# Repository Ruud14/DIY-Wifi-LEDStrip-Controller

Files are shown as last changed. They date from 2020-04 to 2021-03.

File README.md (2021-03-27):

# DIY Wi-Fi LEDStrip Controller

Project status: Work in progress.

DIY Wi-Fi LED strip controller based on the ESP32 chip and MicroPython. Contains step-by-step build guide with links to parts. The controller can be controlled via raw sockets or with an android app.

### Parts
- 1x NodeMCU ESP32 : [eBay LINK 1pc](https://www.ebay.com/itm/Espressif-ESP32-WLAN-Dev-Kit-Board-Development-Bluetooth-Wifi-v1-WROOM32-NodeMCU/253059783728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)
- 3x 1KOhm resistor: [eBay LINK 100pc](https://www.ebay.com/itm/100-pcs-1-4W-0-25W-1-Metal-Film-Resistor-1K-ohm-1Kohm/282033455842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)
- 1x 12v Female DC Power Socket: [EBAY LINK 10pc](https://www.ebay.com/itm/10Pcs-5-5-x-2-1mm-12-V-DC-Power-Supply-Jack-Socket-Female-Panel-Mount-Connector/143449192665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)
- 1x Female strip connector: [EBAY LINK 5pc](https://www.ebay.com/itm/Durable-4Pin-Male-Female-Connector-Wire-Cable-for-3528-5050-SMD-LED-Strip-Light/352235582745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)
- 1x RGB LED strip: [eBay LINK 1pc](https://www.ebay.com/itm/184203854470?ViewItem=&item=184203854470)
- 3x Tip31c transistor: [eBay LINK 10pc](https://www.ebay.com/itm/10-x-TIP31C-TIP31-NPN-Transistor-3A-100V-TO-220-FSC/270984720497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)
- 1x 12v Power Supply Adapter (2A for a 5M long strip): [eBay LINK 1pc](https://www.ebay.com/itm/AC-TO-DC-5V-12V-24V-1A-2A-3A-5A-10A-0-5A-Power-Supply-Adapter-LED-Strip-Light/254344416209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)
- 1x 12v to 5v Converter: [eBay LINK 1pc](https://www.ebay.com/itm/DC-DC-12V-to-5V-6V-9V-2-3A-15W-Converter-Step-Down-2A-3A-15W-Power-Supply-Module/401327863545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)
- 1x PCB. Upload the attached Gerber files to jlcpcb.com. (Minimum amount is 5pc)
- 8x M2.5-3.5 bolts&nuts. 20-30 mm long [eBay LINK](https://www.ebay.com/itm/M2-M2-5-M3-304-Stainless-Steel-Allen-Hex-Socket-Countersunk-Head-Screws-Bolts/282935136527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)
- 2x Simple 5 cm long wire

### Tools
- Soldering iron
- small pliers (or tiny hands)
- 3d printer (optional, you can make everything except for the case.)
- Windows or Linux PC.

# Makers guide
First order all the necessary parts and make sure you have all the required tools.
While waiting for the parts to arrive you can already install a version of [python](https://www.python.org/) on your PC.
Make sure you install version 3.7 or higher.
After installing python you can connect your esp32 board to your PC using a micro USB cable,
install [esptool](https://pypi.org/project/esptool/) and flash your esp32 with the MicroPython firmware. You can find a great guide for all this
over [here](https://docs.micropython.org/en/latest/esp8266/tutorial/intro.html). **Make sure to hold the "Boot" button on the board while writing and erasing flash or it won't work.**

The last thing we should do before we start soldering is put
the [attached scripts](https://github.com/Ruud14/DIY-Wifi-LEDStrip-Controller/tree/master/to_ESP32) on the board.
You can do this with a tool called [ampy](https://learn.adafruit.com/micropython-basics-load-files-and-run-code/install-ampy) .
Simply install ampy by running 'pip3 install adafruit-ampy' in your terminal. After that you can put all the scripts on your board by running:
'ampy --port YOUR_PORT put boot.py',
'ampy --port YOUR_PORT put main.py',
'ampy --port YOUR_PORT put objects.py',

After this you can disconnect your esp32 from your PC and start soldering.
I tried to mark everything on the PCB as good as possible, but you can look at the [pictures](https://github.com/Ruud14/DIY-Wifi-LEDStrip-Controller/tree/master/pictures) if it isn't clear enough.
**One thing you really need to look out for is that the wires of the female strip connector aren't in the correct order.
You need to put the red wire in the hole that says 'R', the green one in the hole that says 'G' and the blue one in the hole that says 'B'.**
**Another thing to note is that the shortest end of the female dc power socket should be connected to the positive end of the board**

*This part is for the ones that are printing the case.
You can download the [attached .stl files](https://github.com/Ruud14/DIY-Wifi-LEDStrip-Controller/tree/master/3d%20models)
convert them to g-code and print them. Make sure you enable support material for the bottom part.*

After everything is done you should check that no soldered connections are touching each other and connect your soldered PCB to power.
Just to check you can scan for nearby Wi-Fi networks on your phone and you should see a network called "LedStrip Setup" if everything is alright.
Now your very own controller is done and you can install the app to control the strip [here](https://github.com/Ruud14/Wifi-LEDStrip-Controller-App).
You can also control the strip by sending raw socket commands in the following format:

(1024,0,0);Fade(0.2);(0,0,0);Wait(0.2)

The string should always start with a RGB color '(r,g,b)'
where the values of r, g and b must be between 0 and 1024.
After a color comes a transition. The two options are 'Fade(x)' and 'Wait(x)' .
A color can only be followed up by a transition and a transition can only be followed up by a color.
Colors and transitions must be separated by a ';'. The string must always end with a transition.

**Just to make sure that the ip of your strip controller doesn't change when the router resets, Reserve the ip addresses of the strip controller in the settings of your router.** You can find the ip of your controller in [The android app](https://github.com/Ruud14/Wifi-LEDStrip-Controller-App) after you added the strip.

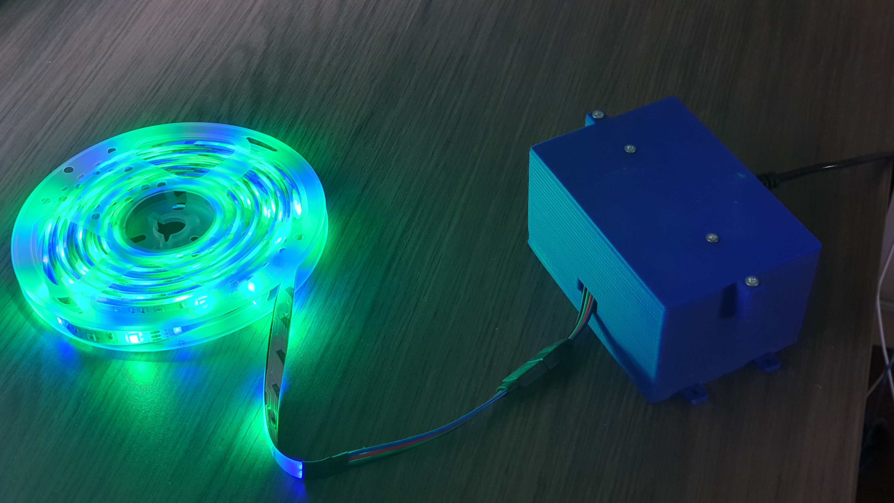
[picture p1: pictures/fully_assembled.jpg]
fully_assembled

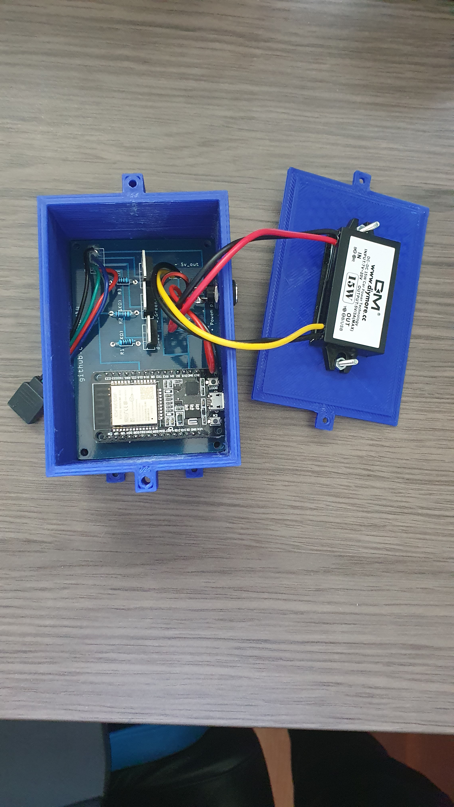
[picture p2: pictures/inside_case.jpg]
inside_case

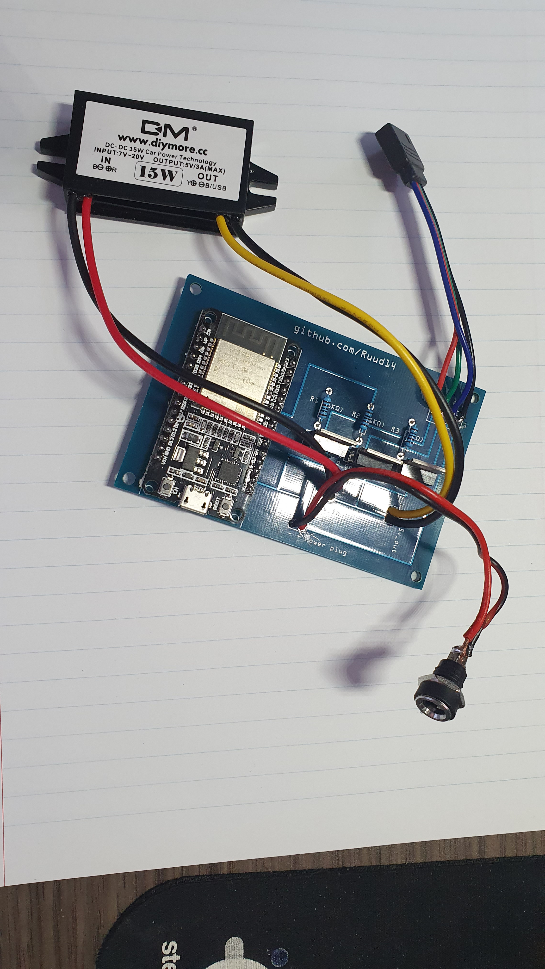
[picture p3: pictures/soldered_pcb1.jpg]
soldered_pcb1


### Additional info.
**What I learned:**
- Working access point networks.
- Working with the esp32 (Had used a esp8266 before).
- Designing a PCB.

Licensed under the [MIT License](https://github.com/Ruud14/DIY-Wifi-LEDStrip-Controller/blob/master/LICENSE)

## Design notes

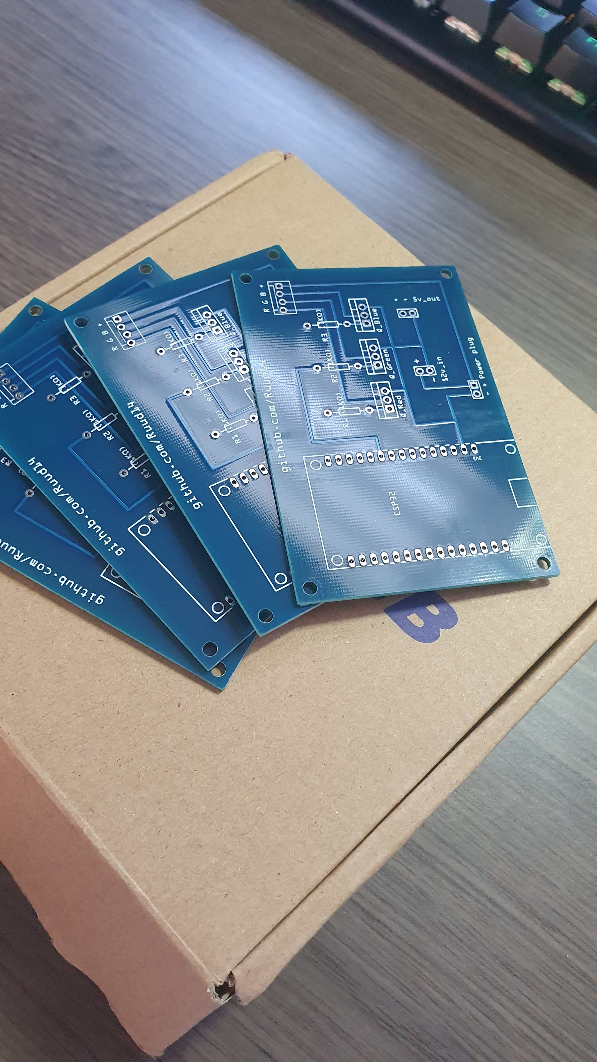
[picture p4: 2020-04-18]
pictures/pcbs.jpg

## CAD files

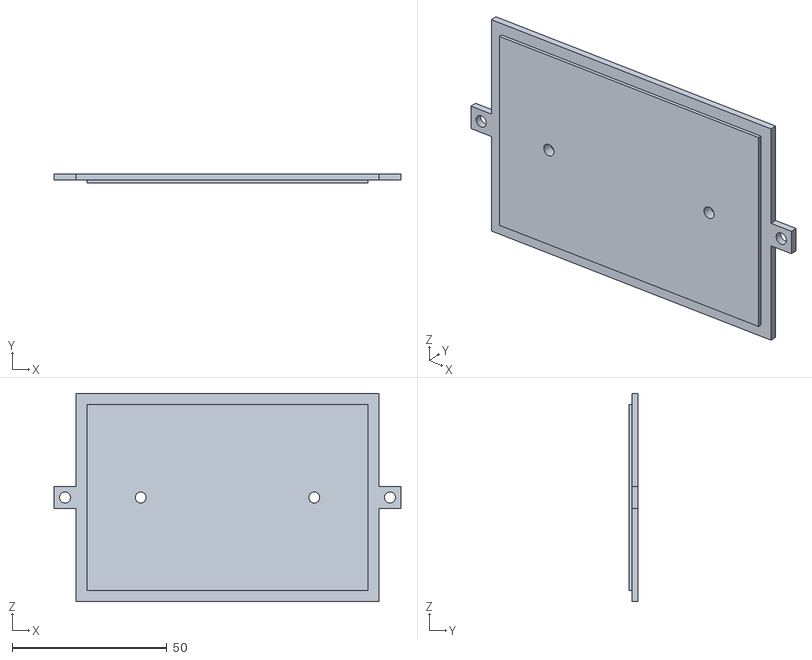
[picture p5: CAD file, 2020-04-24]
3d models/Top.stl
112.2 x 3.06 x 67.3

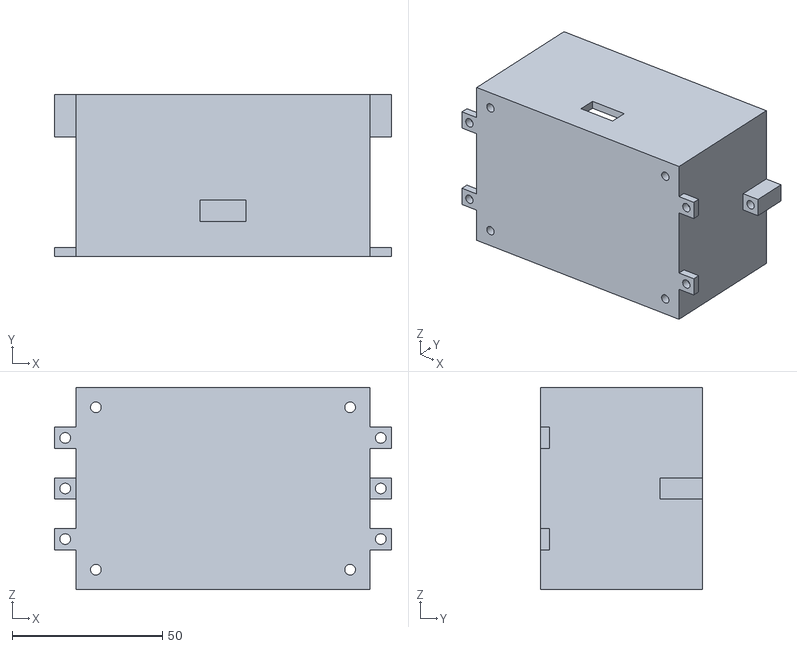
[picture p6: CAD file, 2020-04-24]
3d models/Bottom.stl
112.2 x 54.1 x 67.3

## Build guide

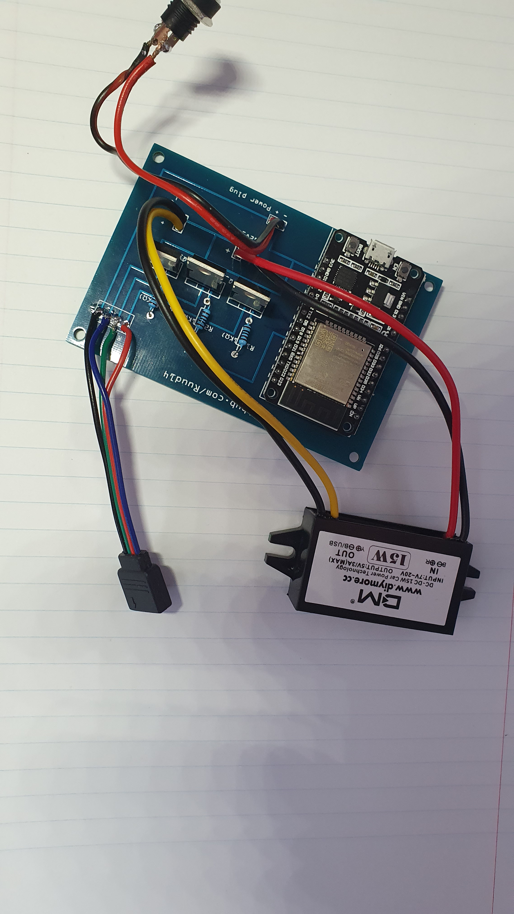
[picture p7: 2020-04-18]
pictures/soldered_pcb2.jpg

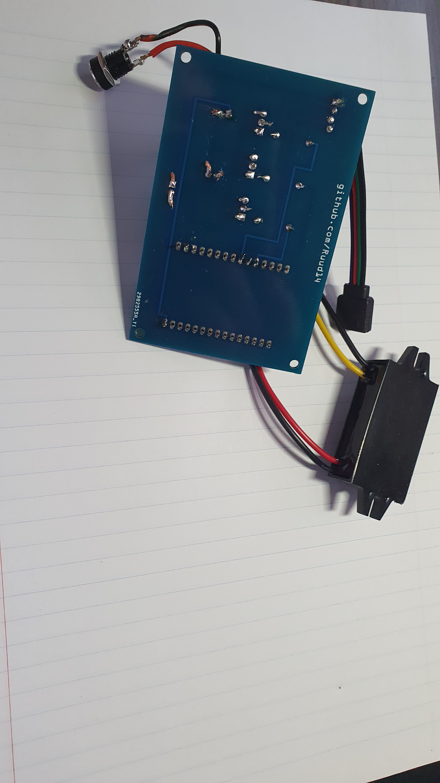
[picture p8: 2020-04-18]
pictures/soldered_pcb3.jpg

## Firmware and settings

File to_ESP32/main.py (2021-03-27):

import _thread
from objects import *
import usocket
import machine
import time
import gc
import os

CONFIGURATION_SAVE_FILE = "configurations.save"
NETWORK_CONFIGURATION_SAVE_FILE = "netconfig.txt"
DATA_PORT = 8778


def create_socket():
    s = usocket.socket()
    s.bind(("0.0.0.0",DATA_PORT))
    s.listen(5)
    return s


# Load the last saved configuration if there is one. Otherwise load a red flashing one.
def get_last_configuration():
    try:
        with open(CONFIGURATION_SAVE_FILE, 'r') as file:
            str_loops = file.readlines()
        config = load_configuration(str_loops[-1])
    except (OSError, IndexError, ValueError):
        config = [Color(1023, 0, 0), Wait(0.2), Color(0, 0, 0), Wait(0.2), Color(1023, 0, 0), Wait(0.2),
                      Color(0, 0, 0), Wait(1.0)]
    return config


def main():
    s = create_socket()
    s.settimeout(2)
    start_loop = get_last_configuration()

    c = Configuration(start_loop, CONFIGURATION_SAVE_FILE)
    _thread.start_new_thread(c.play_forever, ())

    while True:
        try:
            client, addr = s.accept()
            message = client.recv(4096).decode()

            # Reboots the chip.
            if message == "restart":
                machine.reset()
                continue
            elif message == "status":
                if c.stopped:
                    client.send('0')
                else:
                    client.send('1')
                time.sleep(0.1)
                continue
            # Resets network settings and configurations.
            elif message == "reset":
                os.remove(NETWORK_CONFIGURATION_SAVE_FILE)
                os.remove(CONFIGURATION_SAVE_FILE)
                c.stop()
                machine.reset()
                continue
            elif message == "off":
                for i in range(10):
                    c.stop()
                    time.sleep(0.1)
                continue
            elif message.startswith('('):
                str_configuration = message
            else:
                continue
        except OSError:
            continue
        # Close the client if there is one.
        finally:
            try:
                client.close()
            except NameError:
                pass
        c.stop()
        gc.collect()
        # Keep the current loop if the new one is invalid.
        try:
            loop = load_configuration(str_configuration)
            c.loop = loop
            c.validity_check()
        except:
            c.loop = get_last_configuration()
        c.save()
        c.restart()


if __name__ == '__main__':
    main()

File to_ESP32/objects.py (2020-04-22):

import time
import sys
import machine

RED_CONTROL_PIN = 21
GREEN_CONTROL_PIN = 19
BLUE_CONTROL_PIN = 18


def error(arg):
    raise Exception(arg)


# Converts a (saved or received) configuration from a string to the loop argument of the Configuration class.
def load_configuration(str_conf):
    str_loop = str_conf.split(";")
    loop = []
    for x in str_loop:
        if x.startswith("("):
            loop.append(Color(*[int(y)-1 if int(y)==1024 else int(y) for y in x.replace(")","").replace("(","").split(",")]))
        else:
            class_name, duration = x.split("(")
            duration = float(duration.replace(")",""))
            loop.append(getattr(sys.modules[__name__], class_name)(duration))
    return loop


class Color:
    def __init__(self, R, G, B):
        self.validity_check(R, G, B)
        self.set(R, G, B)

    # Sets the current color of the strip.
    def set(self, R, G, B):
        self.R = int(round(R))
        self.G = int(round(G))
        self.B = int(round(B))
        led_strip.set_color(self)

    # Returns the color as r,g,b values.
    def get(self):
        return self.R, self.G, self.B

    # Checks if the R,G,B values are valid.
    def validity_check(self, R, G, B):
        if not R >= 0 or not R <= 1023 or not G >= 0 or not G <= 1023 or not B >= 0 or not B <= 1023:
            error("The value of R, G and B have to be between 0 and 1023: {},{},{}".format(R, G, B))

    def __str__(self):
        return str((self.R, self.G, self.B))


# ---- Transition parent class ---- #
class Transition:
    def __init__(self, duration):
        self.duration = duration
        self.current_color = Color(0, 0, 0)

    # Returns the current color.
    def get(self):
        return self.current_color

    def __str__(self):
        return str(self.__class__.__name__)+"({})".format(self.duration)


# ---- All transitions ----
# Waits for a specific amount of seconds before changing to the next color.
class Wait(Transition):
    def run(self, current_color, next_color):
        self.current_color = current_color
        time.sleep(self.duration)
        self.current_color.set(*next_color.get())


# Slowly fades from one color to another during a specific amount of seconds.
class Fade(Transition):
    def run(self, current_color, next_color):
        self.current_color = current_color
        differences = [0, 0, 0]
        for i in range(3):
            differences[i] = next_color.get()[i] - self.current_color.get()[i]
        iterations = int(self.duration*1000)
        part = 1/iterations
        start = self.current_color.get()

        for i in range(iterations):
            self.current_color.set(start[0] + part * differences[0] * (i+1), start[1] + part * differences[1] * (i+1), start[2] + part * differences[2] * (i+1))
            time.sleep(0.001)
        self.current_color.set(*next_color.get())


# Class representation of the LED strip.
class LedStrip:
    def __init__(self, r_pin, g_pin, b_pin):
        self.red = machine.PWM(machine.Pin(r_pin), freq=5000)
        self.green = machine.PWM(machine.Pin(g_pin), freq=5000)
        self.blue = machine.PWM(machine.Pin(b_pin), freq=5000)

    # Sets the color of the strip.
    def set_color(self, color):
        r,g,b = color.get()
        self.red.duty(r)
        self.green.duty(g)
        self.blue.duty(b)


# Class representation of the configuration running on the strip.
class Configuration:
    def __init__(self, loop, save_file):
        self.save_file = save_file
        self.loop = loop
        self.validity_check()
        self.save()
        self.current_color = Color(*loop[0].get())
        self.stopped = False

    # Goes through self.loop to play the configuration
    def play(self):
        for i, it in enumerate(self.loop):
            if isinstance(it, Transition):
                if self.stopped:
                    break
                try:
                    if i == len(self.loop)-1:
                        it.run(self.current_color, self.loop[0])
                    else:
                        it.run(self.current_color, self.loop[i+1])
                except IndexError:
                    break

    # Keeps running self.play to play the configuration forever
    def play_forever(self):
        while True:
            if not self.stopped:
                self.play()

    # stops running the configuration and turns off the strip.
    def stop(self):
        self.stopped = True
        self.current_color = Color(0, 0, 0)

    # Continues running the configuration.
    def restart(self):
        self.stopped = False

    # Saves the current configuration to storage so it can be run on the next startup.
    def save(self):
        string = ";".join([str(x) for x in self.loop]) + "\n"
        print(string)

        try:
            with open(self.save_file, 'r+') as file:
                last = file.readlines()[-1]
                # only save if the last save isn't the same as this one.
                if not last == string:
                    file.write(string)
            with open(self.save_file, 'r') as file:
                data = file.readlines()
            # save only 5 configurations.
            if len(data) > 5:
                with open(self.save_file, 'w') as file:
                    for line in data[1:]:
                        file.write(line)
        except (OSError, IndexError):
            with open(self.save_file, 'w') as file:
                file.write(string)

    # Checks if the configuration is valid.
    def validity_check(self):
        if not isinstance(self.loop[0], Color):
            error("First element of loop has to be a color.")
        if not isinstance(self.loop[-1], Transition):
            error("Last element of loop has to be a transition. "
                  "This transition is necessary to go back to the first color.")

        prev = 't'
        for it in self.loop:
            if isinstance(it, Color):
                if not prev == 't':
                    error("A color can't be followed up by another color.")
                prev = 'c'
            elif isinstance(it, Transition):
                if not prev == 'c':
                    error("A Transition can't be followed up by another transition.")
                prev = 't'
            else:
                error("{} isn't a color or a transition.".format(str(it)))


# Global LED strip, which can be accessed by every class.
led_strip = LedStrip(RED_CONTROL_PIN, GREEN_CONTROL_PIN, BLUE_CONTROL_PIN)

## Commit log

2020-04-24 Improved 3d models
    [Bottom.stl, Top.stl]
2020-04-24 Turn off strip when resetting
    [main.py]
